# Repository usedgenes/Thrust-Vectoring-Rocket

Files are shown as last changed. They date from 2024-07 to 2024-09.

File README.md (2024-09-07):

# Thrust Vectoring Rocket
 
This is a project for building a thrust vector controlled rocket. The system is designed to fit a rocket booster of diameter 74mm (from Apogee Rockets), and is controlled by an ESP 32 along with a BMI088 IMU and BMP390 for sensor data. The motor used is an F15-0 from Estes, with the low average thrust helping to deal with the relatively weak structural strength of the 3D printed parts. A bluetooth app is used to get data from the flight computer, and can also be used to change the PID coefficients. So far, I've only tested the mechanism on the ground, though I plan to launch it in a rocket soon. 

Link to static test fire:
https://github.com/usedgenes/Thrust-Vectoring-Rocket/blob/main/Testing/gimbal%20test.MOV

There is also an iOS app to control and get data from the flight computer, and is located in the "Rocket" folder. You can open it in XCode and then run it on your own device to test. 

Link to CAD files: https://cad.onshape.com/documents/2ca9fc9211faac09d786cfb3/w/8b61a603854f19ea49b1fde7/e/632ef75d5f14d64c56a16a13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

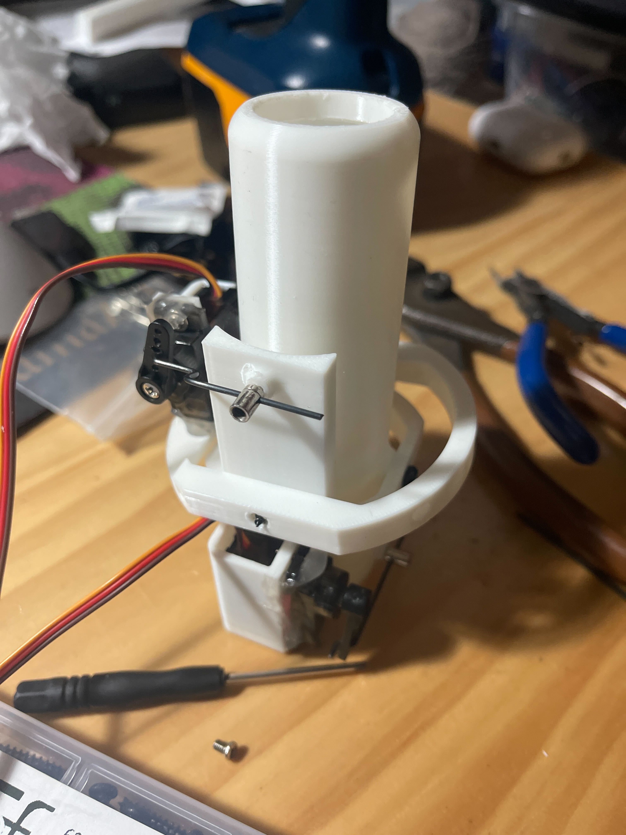
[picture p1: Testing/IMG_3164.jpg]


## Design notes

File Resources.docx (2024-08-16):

vivekvidyarthi99/Rocket-Thrust-Vectoring: Thrust Vectoring for scale-able rockets using a Kalman filter and PID controller. (github.com) (https://github.com/vivekvidyarthi99/Rocket-Thrust-Vectoring)

tomkuttler/TVC-Rocket-Flight-Code: Closed loop thrust vector control software for model rocketry (github.com) (https://github.com/tomkuttler/TVC-Rocket-Flight-Code)

ViktorBash/PID-Control-Loop: Thrust Vector Control Rocket flight control software with PID control loop made in Python and tested in MATLAB (github.com) (https://github.com/ViktorBash/PID-Control-Loop)

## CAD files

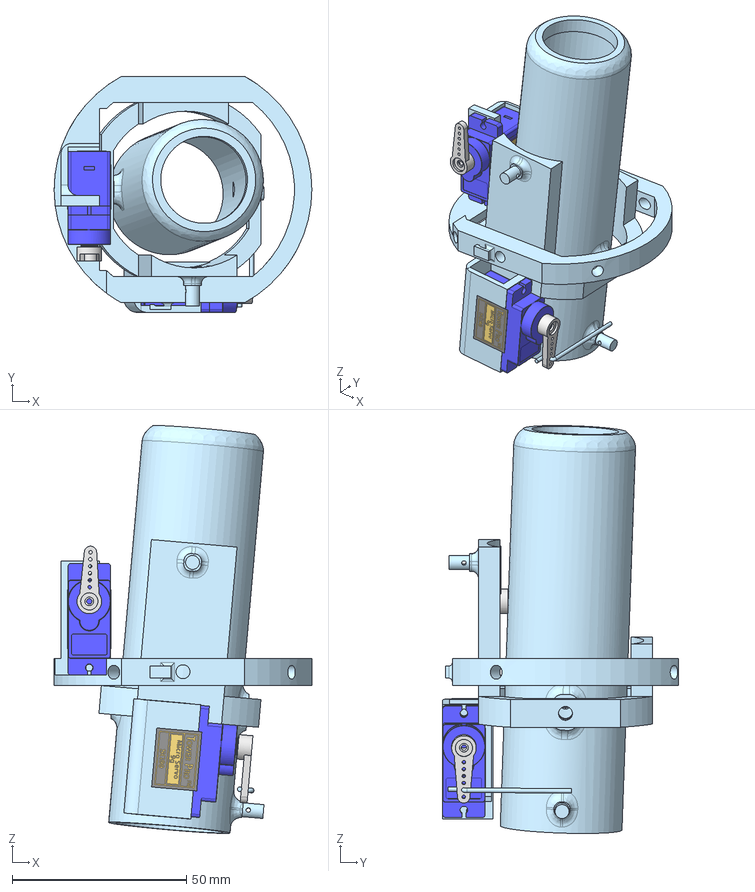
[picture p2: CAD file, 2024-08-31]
Parts/Assembly 1.step
74.0 x 67.9 x 117.1 mm
Outer Axis

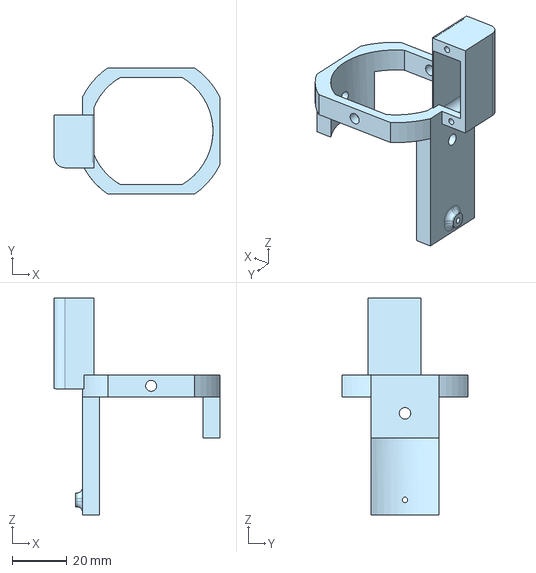
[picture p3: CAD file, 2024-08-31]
Parts/Inner Axis.step
60.3 x 46.0 x 79.0 mm

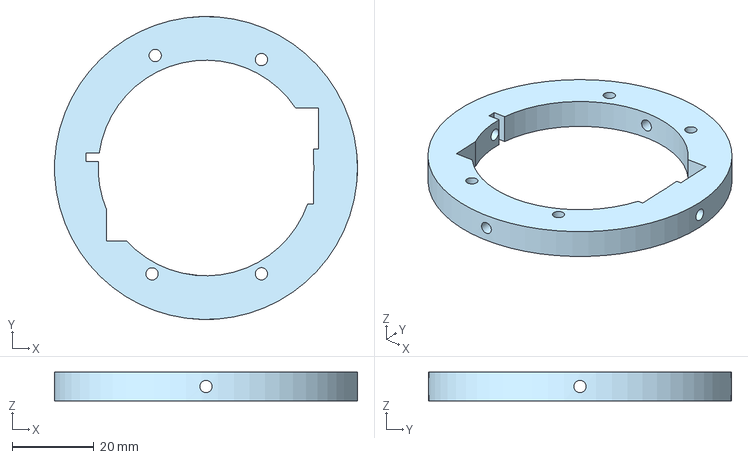
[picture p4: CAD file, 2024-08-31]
Parts/Flight Computer Holder - Flight Computer Holder.step
74.2 x 74.2 x 7.00 mm

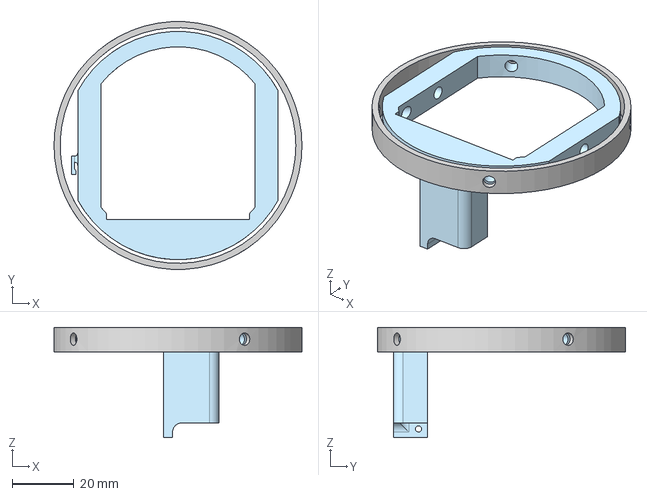
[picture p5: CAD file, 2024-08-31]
Parts/Outer Axis.step
80.4 x 80.3 x 35.8 mm

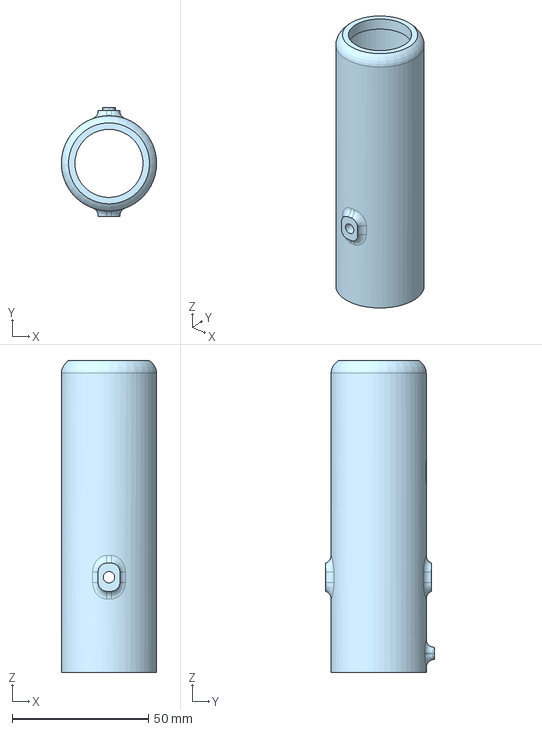
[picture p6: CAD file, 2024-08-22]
Parts/Motor Casing.step
35.0 x 40.0 x 114.6 mm

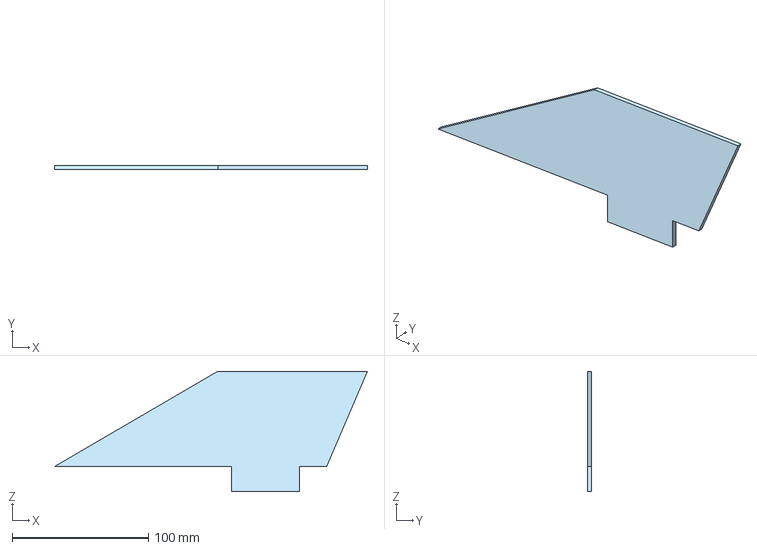
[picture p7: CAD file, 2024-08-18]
Parts/Transition 1.step
230.0 x 3.00 x 88.5 mm

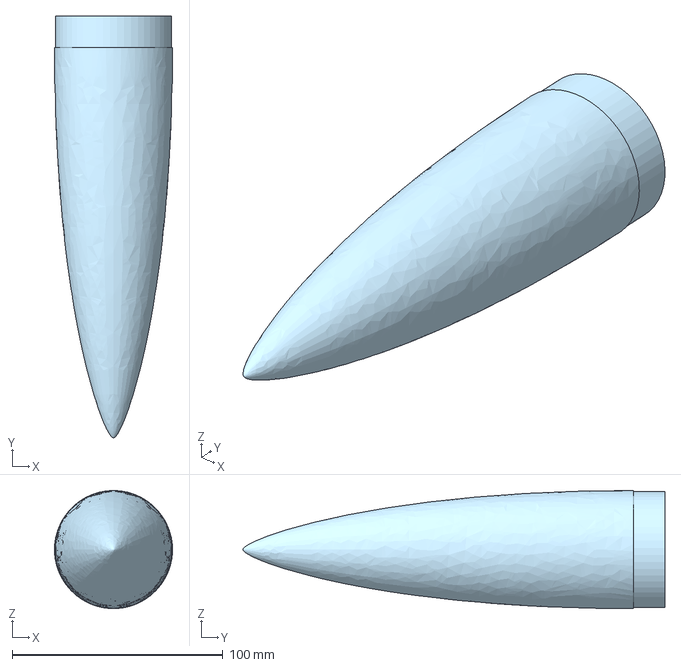
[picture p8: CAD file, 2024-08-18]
Parts/Nose Cone 2.step
56.0 x 200.0 x 55.9 mm

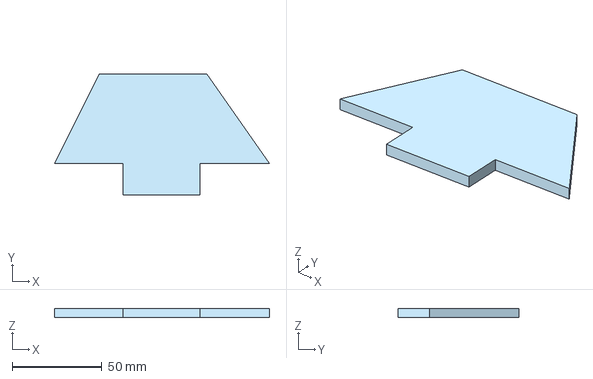
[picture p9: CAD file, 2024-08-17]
Parts/Fin 2.step
120.0 x 67.6 x 5.08 mm

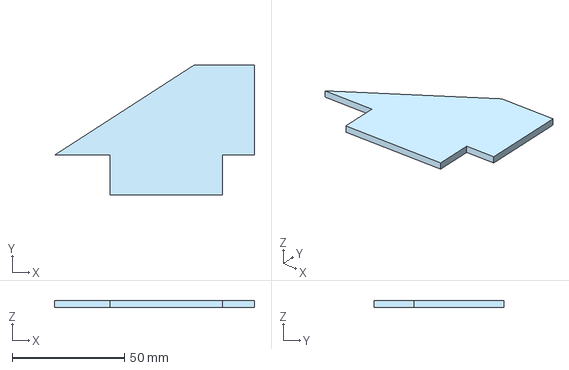
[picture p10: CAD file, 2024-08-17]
Parts/Fin 1.step
89.0 x 57.6 x 3.00 mm

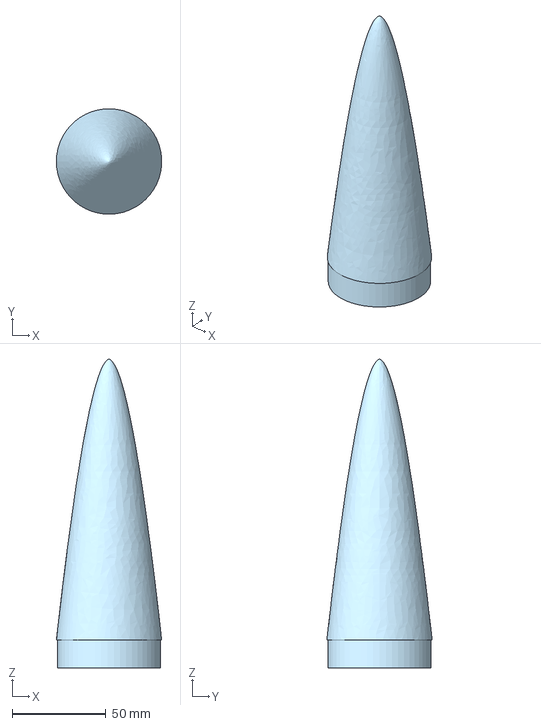
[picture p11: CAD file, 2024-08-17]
Parts/Nose Cone.step
56.2 x 56.3 x 165.0 mm

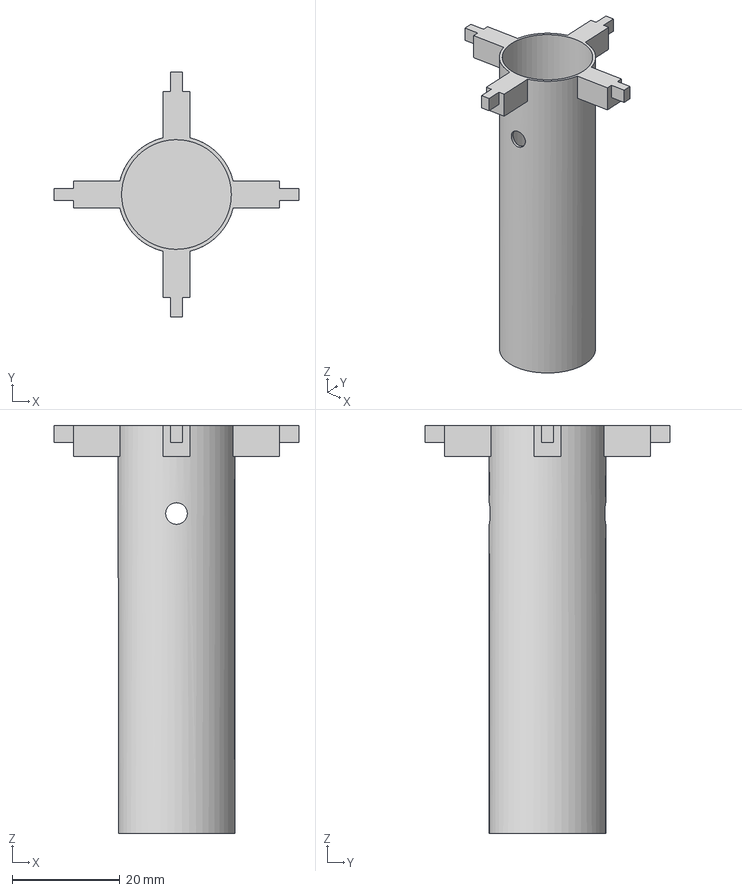
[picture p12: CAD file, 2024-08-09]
Parts/altimeter holder.step
45.3 x 45.3 x 75.6 mm

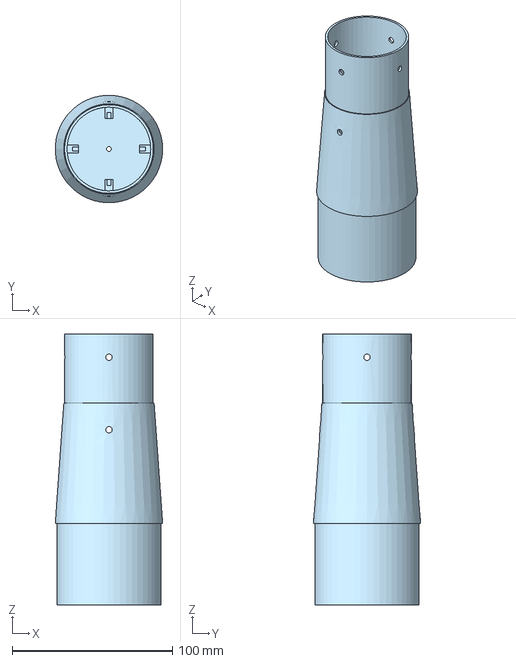
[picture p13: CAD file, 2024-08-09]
Parts/transition.step
66.9 x 66.9 x 168.9 mm

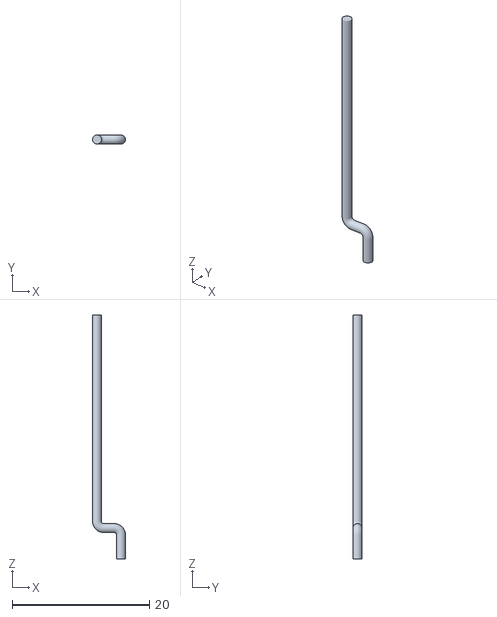
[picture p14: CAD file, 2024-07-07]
Parts/Rod.stl
4.80 x 1.30 x 35.5

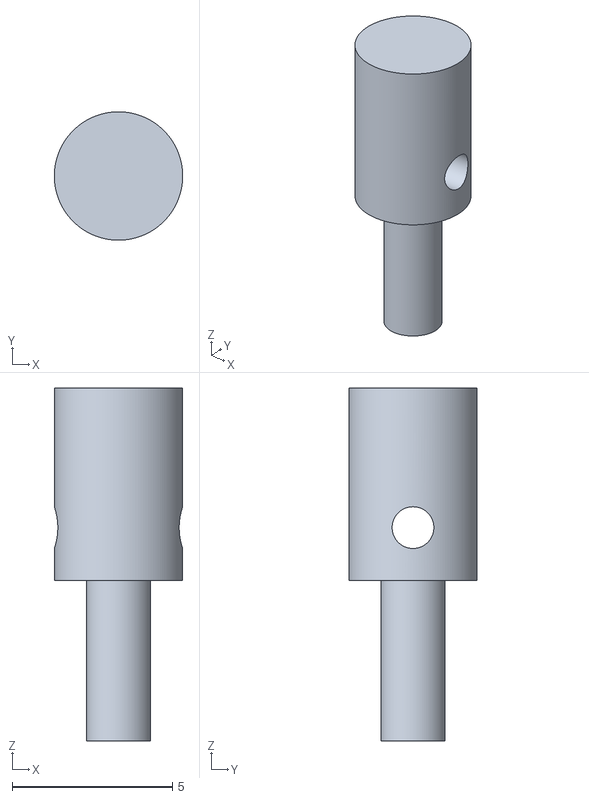
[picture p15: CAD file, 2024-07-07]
Parts/Stopper.stl
4.00 x 4.00 x 11.0

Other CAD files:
Parts/Second Rod.stl

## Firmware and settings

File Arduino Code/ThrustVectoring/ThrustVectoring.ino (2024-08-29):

#include "Bluetooth.h"
#include "IMU.h"
#include "Servos.h"
#include "Altimeter.h"
#include "Calculations.h"
#include "Logger.h"
#include "PID.h"
#include "Utilities.h"

#define SPI1_SCK 5
#define SPI1_MISO 16
#define SPI1_MOSI 17
#define SPI1_CS 21
#define SPI2_SCK 27
#define SPI2_MISO 25
#define SPI2_MOSI 26
#define SPI2_CS 33

#define BLUETOOTH_REFRESH_THRESHOLD 50
#define LAUNCH_ALTITUDE_THRESHOLD_METERS 4
#define MOTOR_BURN_TIME_MILLISECONDS 100000
#define PARACHUTE_EJECTION_VELOCITY_THRESHOLD 3
#define RECOVERY_ALTITUDE_THRESHOLD_METERS 1000

#define ON_PAD_DATA_FREQUENCY 1000
#define TVC_ACTIVE_DATA_FREQUENCY 1000
#define COASTING_DATA_FREQUENCY 1000
#define PARACHUTE_OUT_DATA_FREQUENCY 1000
#define ON_GROUND_DATA_FREQUENCY 1000

#define RAD_TO_DEG 57.29577
#define DEG_TO_RAD 0.01745

SPIClass* vspi = NULL;
SPIClass* hspi = NULL;

Bluetooth bluetooth;
IMU imu;
Servos servos;
Altimeter altimeter;
Calculations kalmanX, kalmanY;
Logger logger;
PID pitchPID, rollPID;
Utilities utilities;

unsigned long currentTime = 0;
unsigned long previousTime = 0;
unsigned long loopTime = 0;

unsigned long lastDataLog = 0;

float currentAltitude = 0;
float currentTemperature = 0;
float currentPressure = 0;
float launchAltitude = 0;
unsigned long motorIgnitionTime = 0;
float previousAltitude = 0;

float accelerometer[] = { 0, 0, 0 };
float gyroscope[] = { 0, 0, 0 };

double roll, pitch;
double kalAngleX, kalAngleY;
double adjustedKalAngleX;

float pitchCommand = 0, rollCommand = 0;
float servo0Position = 0, servo1Position = 0;
float apogee = 0;

bool sendBluetoothData = false;
bool bluetoothConnected = false;
bool armed = false;
bool bluetoothBypassOnPad = false;
bool bluetoothBypassTVCActive = false;
bool bluetoothBypassCoasting = false;
bool bluetoothBypassParachuteOut = false;
bool sendLoopTime = false;
bool sendBluetoothBMI088 = false;
bool sendBluetoothAltimeter = false;
bool sendBluetoothPID = false;
bool sendBluetoothOrientation = false;
bool sendBluetoothServo = false;

void setup() {
  Serial.begin(115200);
  bluetooth.Init(&servos, &imu, &altimeter, &pitchPID, &rollPID, &armed, &bluetoothConnected, &sendLoopTime, &sendBluetoothBMI088, &sendBluetoothOrientation, &sendBluetoothAltimeter, &sendBluetoothPID, &bluetoothBypassOnPad, &bluetoothBypassTVCActive, &bluetoothBypassCoasting, &bluetoothBypassParachuteOut, &sendBluetoothServo);
  while (!bluetoothConnected) {
    delay(1000);
  }
  vspi = new SPIClass(VSPI);
  hspi = new SPIClass(HSPI);
  vspi->begin(SPI1_SCK, SPI1_MISO, SPI1_MOSI, SPI1_CS);
  hspi->begin(SPI2_SCK, SPI2_MISO, SPI2_MOSI, SPI2_CS);
  // utilities.Init();
  kalmanX.Init();
  kalmanY.Init();
  servos.Init();
  pitchPID.Init(45, 0.5, 15);
  rollPID.Init(45, 0.5, 15);
  pitchPID.setSetpoint(0);
  rollPID.setSetpoint(0);
  if (!imu.Init(*hspi)) {
    bluetooth.writeUtilitiesNotifications("IMU Initialization Error");
    Serial.println("IMU Initialization Error");
    while (1) {}
  }
  if (!altimeter.Init(vspi)) {
    bluetooth.writeUtilitiesNotifications("Altimeter Initialization Error");
    Serial.println("BMP390 Initialization Error");
    while (1) {}
  }
  if (!logger.Init(*vspi)) {
    bluetooth.writeUtilitiesNotifications("SD Initialization Error");
    Serial.println("SD Initialization Error");
  }

  // utilities.initialized();

  while (!armed) {
    dataLoop();
    logData(ON_PAD_DATA_FREQUENCY);
  }

  roll = atan2(accelerometer[1], accelerometer[2]) * RAD_TO_DEG;
  pitch = atan(-accelerometer[0] / sqrt(accelerometer[1] * accelerometer[1] + accelerometer[2] * accelerometer[2])) * RAD_TO_DEG;
  kalmanX.setAngle(roll);  // Set starting angle
  kalmanY.setAngle(pitch);

  previousTime = 0;
  launchAltitude = altimeter.getAltitude();
  bluetooth.writeUtilitiesNotifications("Launch Altitude: " + String(launchAltitude));
  logger.logEvent("Launch Altitude: " + String(launchAltitude) + ", " + String(millis()));
  Serial.println("Launch Altitude: " + String(launchAltitude));

  // utilities.armed();
  bluetooth.writeUtilitiesEvents("On Pad");
  logger.logEvent("On Pad, " + String(millis()));
  Serial.println("On Pad");
  while (altimeter.getFilteredAltitude() - launchAltitude < LAUNCH_ALTITUDE_THRESHOLD_METERS && !bluetoothBypassOnPad) {
    onPad();
  }

  motorIgnitionTime = millis();
  bluetooth.writeUtilitiesEvents("TVC Active");
  logger.logEvent("TVC Active, " + String(millis()));
  Serial.println("Thrust Vector Active");
  while (millis() - motorIgnitionTime < MOTOR_BURN_TIME_MILLISECONDS && !bluetoothBypassTVCActive) {
    thrustVectorActive();
  }

  bluetooth.writeUtilitiesEvents("Coasting");
  logger.logEvent("Coasting, " + String(millis()));
  Serial.println("Coasting");
  while ((altimeter.getFilteredAltitude() - previousAltitude) / loopTime < PARACHUTE_EJECTION_VELOCITY_THRESHOLD && !bluetoothBypassCoasting) {
    coasting();
  }

  logger.logEvent("Launch Altitude: " + String(currentAltitude) + ", " + String(millis()));
  deployParachute();

  bluetooth.writeUtilitiesEvents("Parachute Out");
  logger.logEvent("Parachute Out, " + String(millis()));
  Serial.println("Parachute Out");
  while (altimeter.getFilteredAltitude() - launchAltitude > RECOVERY_ALTITUDE_THRESHOLD_METERS && !bluetoothBypassParachuteOut) {
    parachuteOut();
  }

  bluetooth.writeUtilitiesEvents("Touchdown");
  logger.logEvent("Touchdown, " + String(millis()));
  Serial.println("Touchdown");
  while (true) {
    touchdown();
  }
}

void loop() {
}

void onPad() {
  dataLoop();
  logData(ON_PAD_DATA_FREQUENCY);
}

void thrustVectorActive() {
  dataLoop();
  pitchCommand = pitchPID.ComputeCorrection(kalAngleY * DEG_TO_RAD, loopTime);
  rollCommand = rollPID.ComputeCorrection(adjustedKalAngleX * DEG_TO_RAD, loopTime);
  servo0Position = servos.writeGimbalServoPosition(0, pitchCommand);
  servo1Position = servos.writeGimbalServoPosition(1, rollCommand);
  logger.logData("PID Log\t" + String(currentTime) + "\t" + String(pitchCommand) + "\t" + String(rollCommand));
  Serial.println("Pitch Command: " + String(pitchCommand));
  Serial.println("Roll Command: " + String(rollCommand));
  logData(TVC_ACTIVE_DATA_FREQUENCY);
}

void coasting() {
  dataLoop();
  logData(COASTING_DATA_FREQUENCY);
}

void deployParachute() {
  servos.openParachuteServo();
}

void parachuteOut() {
  dataLoop();
  logData(PARACHUTE_OUT_DATA_FREQUENCY);
}

void touchdown() {
  dataLoop();
  logData(ON_GROUND_DATA_FREQUENCY);
  utilities.readApogee(apogee);
}

void dataLoop() {
  currentTime = millis();
  loopTime = millis() - previousTime;
  previousTime = currentTime;
  float dt = loopTime / 1000.0;

  imu.getIMUData(accelerometer, gyroscope);

  roll = atan2(accelerometer[1], accelerometer[2]) * RAD_TO_DEG;
  pitch = atan(-accelerometer[0] / sqrt(accelerometer[1] * accelerometer[1] + accelerometer[2] * accelerometer[2])) * RAD_TO_DEG;
  double gyroXrate = gyroscope[0] / 131.0;  // Convert to deg/s
  double gyroYrate = gyroscope[1] / 131.0;  // Convert to deg/s
  if ((roll < -90 && kalAngleX > 90) || (roll > 90 && kalAngleX < -90)) {
    kalmanX.setAngle(roll);
    kalAngleX = roll;
  } else {
    kalAngleX = kalmanX.getAngle(roll, gyroXrate, dt);  
  }
  if (abs(kalAngleX) > 90) {
    gyroYrate = -gyroYrate;  // Invert rate, so it fits the restriced accelerometer reading
  }
  kalAngleY = kalmanY.getAngle(pitch, gyroYrate, dt);
  if(kalAngleX < 0) {
    adjustedKalAngleX = kalAngleX + 180;
  } else {
    adjustedKalAngleX = kalAngleX - 180;
  }


  currentAltitude = altimeter.getAltitude();
  altimeter.getTempAndPressure(currentTemperature, currentPressure);
}

void logData(int dataLoggingFrequencyInMilliseconds) {
  if (millis() - lastDataLog >= dataLoggingFrequencyInMilliseconds) {
    lastDataLog = millis();
    if (sendBluetoothBMI088) {
      Serial.println("Sending Bluetooth BMI088");
      bluetooth.writeIMU("90" + String(accelerometer[0]));
      bluetooth.writeIMU("91" + String(accelerometer[1]));
      bluetooth.writeIMU("92" + String(accelerometer[2]));
      bluetooth.writeIMU("93" + String(gyroscope[0]));
      bluetooth.writeIMU("94" + String(gyroscope[1]));
      bluetooth.writeIMU("95" + String(gyroscope[2]));
    }
    if (sendBluetoothOrientation) {
      Serial.println("Sending Bluetooth Orientation");
      bluetooth.writeIMU("96" + String(kalAngleY));
      bluetooth.writeIMU("97" + String(kalAngleX));
    }
    if (sendBluetoothAltimeter) {
      Serial.println("Sending Bluetooth Altimeter");
      bluetooth.writeAltimeter("90" + String(currentAltitude));
      bluetooth.writeAltimeter("91" + String(currentTemperature));
      bluetooth.writeAltimeter("92" + String(currentPressure));
    }
    if (sendBluetoothPID) {
      Serial.println("Sending Bluetooth PID");
      bluetooth.writePID("90" + String(pitchCommand));
      bluetooth.writePID("91" + String(rollCommand));
    }
    if (sendLoopTime) {
      Serial.println("Sending Bluetooth Loop Time");
      bluetooth.writeUtilities("90" + String(loopTime));
    }
    if (sendBluetoothServo) {
      Serial.println("Sending Bluetooth Servo");
      bluetooth.writeServo("90" + String(servo0Position));
      bluetooth.writeServo("91" + String(servo1Position));
    }
    logger.logData("Data log\t" + String(currentTime) + "\t" + String(accelerometer[0]) + "\t" + String(accelerometer[1]) + "\t" + String(accelerometer[2]) + String(gyroscope[0]) + "\t" + String(gyroscope[1]) + "\t" + String(gyroscope[2]) + "\t" + String(currentAltitude));
    printToSerial();
  }
}

void printToSerial() {
  // Serial.println("Accelerometer: " + String(accelerometer[0]) + "\t" + String(accelerometer[1]) + "\t" + String(accelerometer[2]));
  // Serial.println("Gyroscope: " + String(gyroscope[0]) + "\t" + String(gyroscope[1]) + "\t" + String(gyroscope[2]));
  // Serial.println("Pitch: " + String(pitch) + "\tRoll: " + String(roll));
  Serial.println("Pitch: " + String(kalAngleY) + "\tRoll: " + String(adjustedKalAngleX));
  // Serial.println("Altitude: " + String(currentAltitude) + "\tTemperature: " + String(currentTemperature) + "\tPressure: " + String(currentPressure));
}

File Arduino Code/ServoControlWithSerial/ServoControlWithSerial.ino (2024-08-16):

#include <ESP32Servo.h>

#define BMP_SCK 13
#define BMP_MISO 12
#define BMP_MOSI 11
#define BMP_CS 10

#define SEALEVELPRESSURE_HPA (1013.25)
Servo myservo;
int num;
void setup() {
  Serial.begin(115200);
  myservo.attach(23);
  // Set up oversampling and filter initialization
}


void loop() {


while(Serial.available()>0)
{
num= Serial.parseInt();
Serial.println(num);
}
myservo.write(num);


}

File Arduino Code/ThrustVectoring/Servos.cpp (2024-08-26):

#include "Servos.h"

void Servos::Init() {
  for (int i = 0; i < 2; i++) {
    gimbalServos[i].write(gimbalServoStartingPosition[i]);
    gimbalServos[i].attach(gimbalServoPins[i]);
    gimbalServos[i].write(gimbalServoStartingPosition[i]);
  }
  parachuteServo.write(parachuteServoOpenPosition);
  parachuteServo.attach(PARACHUTE_SERVO_PIN);
  parachuteServo.write(parachuteServoOpenPosition);
}

void Servos::homeGimbalServos() {
  for (int i = 0; i < 2; i++) {
    gimbalServos[i].write(gimbalServoStartingPosition[i]);
  }
}

void Servos::circleGimbalServos() {
  Serial.println("Circling Gimbal");
  for (int num = 0; num <= 360; num += 20) {
    gimbalServos[0].write((maxGimbalPosition * sin(3.14 * num / 180)) + gimbalServoStartingPosition[0]);
    gimbalServos[1].write((maxGimbalPosition * cos(3.14 * num / 180)) + gimbalServoStartingPosition[1]);
    delay(25);
  }
}

int Servos::getMaxGimbalPosition() {
  return maxGimbalPosition;
}

void Servos::getGimbalServosStartingPositions(int output[]) {
  output[0] = gimbalServoStartingPosition[0];
  output[1] = gimbalServoStartingPosition[0];
}

void Servos::setGimbalServosStartingPosition(int servoNumber, int position) {
  gimbalServoStartingPosition[servoNumber] = position;
  Serial.println("Servo Starting Position: " + String(gimbalServoStartingPosition[0]) + " " + String(gimbalServoStartingPosition[1]));
}

void Servos::bluetoothWriteGimbalServoPosition(int servoNumber, int position) {
  gimbalServos[servoNumber].write(position);
  gimbalServos[0].write(100);
}

float Servos::writeGimbalServoPosition(int servoNumber, float position) {
  int pos = (int) position;
  if (pos > maxGimbalPosition) {
    pos = maxGimbalPosition;
  }
  if (pos < -maxGimbalPosition) {
    pos = -maxGimbalPosition;
  }
  gimbalServos[servoNumber].write(gimbalServoStartingPosition[servoNumber] + pos);
  return pos;
}

void Servos::openParachuteServo() {
  parachuteServo.write(parachuteServoOpenPosition);
  Serial.println("Opened Parachute");
}

void Servos::closeParachuteServo() {
  parachuteServo.write(parachuteServoClosedPosition);
  Serial.println("Closed Parachute");
}

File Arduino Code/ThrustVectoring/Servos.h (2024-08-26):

#ifndef SERVOS_H_
#define SERVOS_H_

#include "ESP32Servo.h"

class Servos {
private:
  #define PARACHUTE_SERVO_PIN 13
  Servo gimbalServos[2];
  Servo parachuteServo;
  int gimbalServoPins[2] = { 23, 22 };
  int gimbalServoStartingPosition[2] = { 90, 90 };
  int maxGimbalPosition = 15;
  int parachuteServoOpenPosition = 140;
  int parachuteServoClosedPosition = 50;
public:
  void Init();
  void getGimbalServosStartingPositions(int output[]);
  void setGimbalServosStartingPosition(int servoNumber, int position);
  void bluetoothWriteGimbalServoPosition(int servoNumber, int position);
  float writeGimbalServoPosition(int servoNumber, float position);
  void openParachuteServo();
  void closeParachuteServo();
  void homeGimbalServos();
  void circleGimbalServos();
  int getMaxGimbalPosition();
};


#endif

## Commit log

2024-07-14 Added Python Simulation
    [AeroTech_F42T_L.csv, AeroTech_F67W.csv]
2024-07-18 Added Arduino Simulation
2024-08-09 Edited Files
    [altimeter holder.step, transition.step]
